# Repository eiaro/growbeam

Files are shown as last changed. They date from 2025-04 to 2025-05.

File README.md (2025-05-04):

# GrowBeam

> A high-efficiency, open-source grow light module for indoor gardeners and hardware hackers.









**GrowBeam** is a modular open-source grow light system designed for indoor gardens, hydroponic setups, and controlled environment agriculture. Each module combines high-efficiency white and deep red LEDs to provide a balanced light spectrum optimized for plant growth.

**NOTE** A test batch is currently ordered. Details to follow soon(tm).

---

## 🌱 Features

- Modular and scalable design
- Uses Samsung LM301H (white) and LUXEON SunPlus 2835 (660 nm red) LEDs
- Designed for 42 V DC input (constant current)
- Simple current-limiting resistor configuration
- Passive cooling (no fans required)
- Easy to manufacture and assemble

## 💡 Light Output & Efficiency

GrowBeam is designed to deliver high photosynthetically active radiation (PAR) while consuming minimal power. Below is a breakdown of light performance based on actual component data:

These values are based on typical LED performance from manufacturer datasheets under standard current levels.

### 🔢 Estimated Output (Per Module)

| Component | Qty | PPF per LED (μmol/s) | Total PPF (μmol/s) |
|---|-----|---|---|
| Samsung LM301H (white) | 72  | ~0.56 | ~40 |
| LUXEON 2835 Deep Red (660 nm) | 15  | ~0.60 | ~9 |
| **Total** | – | – | **~49 μmol/s** |

- **Power consumption:** ~19 W  
- **Photosynthetic Photon Efficacy (PPE):** ~2.60 μmol/J

---

### 🔁 Comparison with Other Light Sources

| Light Source | Power | PPF (μmol/s) | PPE (μmol/J) | Notes |
|---|---|---|---|---|
| **GrowBeam** | ~19 W | ~49 | ~2.6 | High-efficiency DIY module ✅ |
| HPS 400W | 400 W  | ~550 | ~1.4 | High heat, low efficiency ❌ |
| Generic LED Panel (20W) | 20 W | ~15–20 | ~0.75–1.0 | Often misleading specs ❌ |
| T5 Fluorescent Tube (24W) | 24 W | ~28 | ~1.2 | Narrow spectrum, low efficacy ❌ |
| Commercial Grow LED (LM301H) | 100 W | ~270 | ~2.7 | Comparable to GrowBeam ✅ |

---

GrowBeam matches the efficiency of premium grow lights using open hardware and off-the-shelf components — making it a great choice for small to medium-scale indoor growers.

---

## 🛠️ Hardware Overview

Each GrowBeam module contains:
- 6 LED strings with 12 × Samsung LM301H (white)
- 1 LED string with 15 × LUXEON SunPlus 2835 Deep Red

All strings are powered by a shared 42 V DC constant current source and operate at approx. 65 mA per string.

## 📋 Bill of Materials (BoM)

You’ll find a complete part list in `hardware/bom.csv`.  
Key components include:

- 72 × Samsung LM301H white LEDs
- 15 × LUXEON SunPlus 2835 Deep Red LEDs
- Al MCPCB (196 × 35 mm, aluminum-backed recommended)

---

## 📂 Repository Structure
```
growbeam/
├── hardware/
│   ├── kicad_project/           # Contains .kicad_pro, .kicad_sch, .kicad_pcb files, etc.
│   ├── exports/                 # Gerber files, BOM, pick & place, and fabrication outputs
│   └── bom.csv                  # Human-readable bill of materials (optional auto-generated)
├── docs/                        # Additional documentation, test results, diagrams
├── images/                      # Renders, module photos, screenshots
├── LICENSE                      # CERN-OHL v2-S license file
├── README.md                    # Project description and usage guide
├── .gitignore                   # Ignore KiCad backups and build artifacts
└── CONTRIBUTING.md              # (Optional) Contribution guidelines
```

---

## 🧪 Getting Started

1. Clone the repository:  
   `git clone https://github.com/eiaro/growbeam.git`
2. Open the KiCad project in `hardware/kicad_project/`
3. Order parts using the BOM (`hardware/bom.csv`)
4. Assemble and test each module with a 24 V power supply

---

## 📸 Gallery

*(Add photos or renders here)*  
Module example

---

## 📄 License

This project is licensed under the **CERN Open Hardware License v2-S (Strongly Reciprocal)**.  
See the [LICENSE](./LICENSE) file for full terms.

You are free to use, modify, manufacture, and distribute this project, provided that all modifications remain open under the same license.

---

## 🤝 Contributing

Contributions, improvements, and bug reports are welcome!  
If you build your own GrowBeam modules, feel free to share them via issues or pull requests.

## 🙏 Acknowledgements

- Samsung and Lumileds for their detailed datasheets and high-quality horticulture LEDs.
- Open Source Hardware community for inspiration and resources.

## 🌐 Community & Contact

Questions, ideas, or want to showcase your build?  
Open an [issue](https://github.com/eiaro/growbeam/issues) or reach out via [@eiaro](https://github.com/eiaro).

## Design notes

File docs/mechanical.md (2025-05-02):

# 🏗️ Mechanical Design

Modules are mounted on a frame made from aluminum profiles.

## Frame Specification

- 2 vertical and 3 horizontal aluminum profiles
- Fits 5 × 5 modules with even spacing
- Center mounting plate for hanging or support

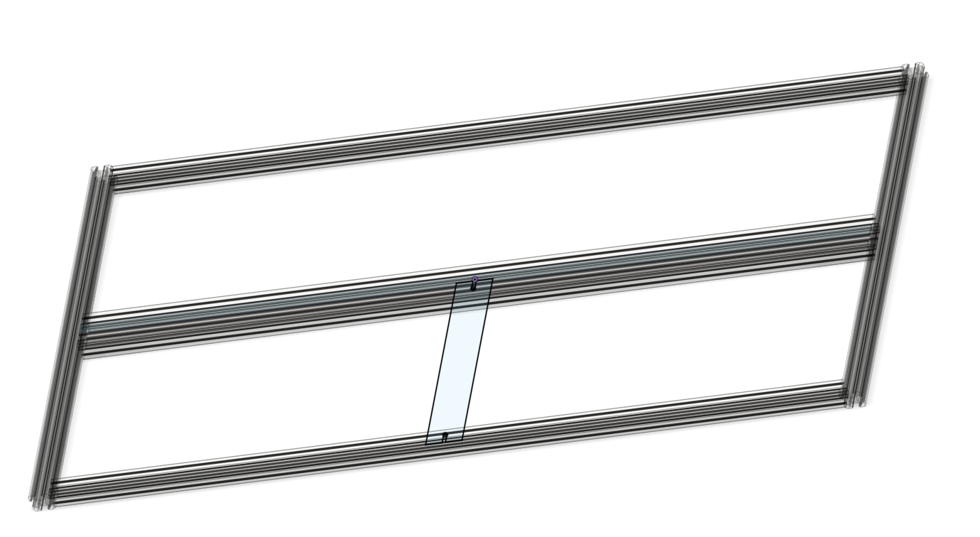
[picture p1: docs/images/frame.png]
Frame


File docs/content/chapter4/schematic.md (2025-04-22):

---
title: "Schematic Design"
weight: 51
---

This section provides an overview of the schematic design for a single GrowBeam LED module.

---

## 📐 Schematic Overview

Schematic

The full schematic is also available as an [PDF file](https://github.com/eiaro/growbeam/blob/main/hardware/exports/schematic.pdf).

---

## 🧾 Bill of Materials (BOM)

The full bill of materials is included as a CSV file:

📄 `hardware/exports/bom.csv`

This file lists all LEDs, resistors, and other components used in each module.

---

## 📏 Resistor Selection Rationale

Each LED string is limited by its own resistor. The values are chosen based on the number of LEDs in series and their forward voltages, using a basic Ohm's Law calculation:

$$
R = \frac{V_{\text{supply}} - V_{\text{LEDs}}}{I}
$$

Where:
- $ V_{\text{supply}} $ is the total supply voltage (24 V)
- $ V_{\text{LEDs}} $ is the combined forward voltage of the LED string
- $ I $ is the target current

| Resistor | LED Count | Estimated \( V_{\text{LEDs}} \) | Resistor Value | Target Drop | Expected Current |
|---|---|---|---|---|---|
| R1–R3 | 7 LEDs | $ 2.75 \text{V} \times 7 = 19.25 \text{V} $ | 75 Ω | ~4.5 V | ~60 mA |
| R4 | 8 LEDs | $ 2.6 \text{V} \times 8 = 20.8 \text{V} $  | 51 Ω | ~3.2 V | ~63 mA |

---

### 🔧 Power Rating

Each resistor needs to dissipate some power:

$$
P = V \times I
$$

For R1–R3:

$$
P \approx 4.5 \text{V} \times 0.06 \text{A} \approx 0.27 \text{W}
$$

For R4:

$$
P \approx 3.2 \text{V} \times 0.063 \text{A} \approx 0.2 \text{W}
$$

To ensure thermal margin and longevity, **0.5 W resistors** are recommended.

---

### ✅ Why Passive Current Limiting?

- No need for active LED drivers
- Easy to test with a multimeter
- Predictable and reliable
- Well-suited for low/medium power modules like GrowBeam

This approach keeps things simple, repairable, and cheap — without sacrificing stability or performance.

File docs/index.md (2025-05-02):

# 🌱 GrowBeam – LED Modules for Plant Lighting

GrowBeam is a modular LED lighting system designed for plant growth. The system consists of 2 × 5 modules mounted on an aluminum frame, powered by a constant current driver from Meanwell.

## Contents

- [Electrical Design](electrical.md)
- [Mechanical Design](mechanical.md)
- [Production](production.md)

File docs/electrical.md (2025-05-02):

# 💡 Electrical Design

## Power Supply

- **Driver:** Meanwell ELG-240-42AB-3Y  
- **Mode:** Constant current  
- **Nominal Output:** 240W @ 42VDC  
- **Set Output Current:** 4.55 A  
- **Configured for 10 modules (5 + 5)**

## LED Configuration

Each module contains:
- 6 strings × 12 white LEDs (SPMWHD32AMH0XAMAPL)
- 1 string × 15 deep red LEDs (L1SP-DRD0002800000)
- Total: 7 LED strings per module, all driven in parallel

Current per module:
- 4.55 A / 10 modules = 455 mA per module
- 455 mA / 7 strings ≈ **65 mA per string**

## Forward Voltage (per string)

| Type | LEDs in series | Est. Vf @ 65 mA | Voltage |
|---|---|---|---|
| White | 12 | ~3.2 V | ~38.4 V |
| Deep Red | 15 | ~2.3 V | ~34.5 V |

All well within the driver's 42 V output limit ✅

## Power and Light Output Per Module

| Type | Count | Current | Power  | Output |
|---|---|---|---|---|
| White LEDs | 72 | 6×65 mA | ~9.9 W | ~1870 lumens |
| Red LEDs | 15 | 1×65 mA | ~2.3 W | ~1.5 W radiant (660 nm) |
| **Total**  | – | 455 mA  | ~12.2 W| ~1870 lm + 1.5 W red |

## System Totals (10 Modules)

- **Total Current:** 4.55 A
- **Total Power:** ~122 W
- **Luminous Output:** ~18,700 lumens
- **660 nm Radiant Power:** ~15 W

## PPF (Photosynthetic Photon Flux)

- White: 1870 lm / 70 ≈ **26.7 μmol/s**
- Red: 1.5 W × 4.58 μmol/s/W ≈ **6.87 μmol/s**
- **PPF per module:** ~33.6 μmol/s
- **Total PPF (10 modules):** **~336 μmol/s**

## PPFD in 90×60 cm Grow Tent

Tent area: 0.9 m × 0.6 m = **0.54 m²**

\[
\text{PPFD} = \frac{336\,μmol/s}{0.54\,m²} ≈ 	extbf{622 μmol/m²/s}
\]

### Summary

| Application | Recommended PPFD | Your PPFD | Outcome |
|---|---|---|---|
| Microgreens / Lettuce | 100–400 | ✅ 622 | Excellent growth |
| Tomatoes / Peppers | 600–900 | ✅ 622 | Very good / near optimal |
| Cannabis Flowering | 800–1000 | ⚠️ 622 | Slightly low, still usable |

This system provides powerful and efficient lighting for high-performance plant growth in a compact 90×60 cm grow space.

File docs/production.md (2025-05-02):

# 🔧 Production

## PCB

- PCB size: 196 mm × 35 mm
- Mounting holes for screw attachment to the frame
- Silkscreen with LED type and polarity

## Assembly

- LEDs are mounted using reflow soldering
- Modules are screwed to the aluminum frame
- Wires are soldered and connected to +VDC and –VDC

## Operation & Safety

- The system is powered only via Meanwell ELG-240-42AB-3Y
- Ensure proper heat dissipation via the frame and/or heatsinks
- Do not operate without connected load

## Future Plans

- Temperature monitoring per module
- PWM dimming via analog input on the driver
- Sensor-based light control

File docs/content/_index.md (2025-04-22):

---
title: GrowBeam
description: Modular LED lighting system for horticulture
---

# 🌱 GrowBeam

GrowBeam is an open hardware project focused on building **modular, efficient, and DIY-friendly LED lighting** for indoor horticulture. Whether you're growing microgreens on a windowsill or managing a full-sized grow tent, GrowBeam aims to provide:

- 🧩 Modular design to fit any tent or tray size  
- 💡 High-efficiency horticulture-grade LEDs  
- 🔧 Simple, fanless thermal design  
- 🛠️ Fully documented: schematics, BOM, 3D models, and rationale  

---

## 🚀 Getting Started

Check the [Getting Started](/chapter1) section to set up the hardware or explore the system design under [Components & Technologies](/chapter4).

---

## 📚 Structure

- **[Background & Motivation](/chapter2)** — Why this project exists
- **[Components](/chapter3)** — LED types, power delivery, mechanical parts
- **[Design & Decisions](/chapter4)** — What we chose and why
- **[Schematic](/chapter4/schematic)** — Circuit overview and BOM
- **[Results & Future](/chapter5)** — Performance, learnings, and roadmap

---

## 💬 Contribute or Learn More

GrowBeam is open to contributions! You can:

- Fork the [GitHub repo](https://github.com/eiaro/growbeam)
- Open issues, suggest improvements, or document your own builds
- Join the discussion and help improve open horticulture lighting!

---

> ⚠️ **Disclaimer**: This project is experimental. Always test electronics for safety and suitability before long-term use in grow environments.

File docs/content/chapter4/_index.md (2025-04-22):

---
title: "Chapter 4 - Design and Decisions"
weight: 50
---

This section documents the design strategies and component choices that were evaluated during the early phases of the GrowBeam project, and why they were ultimately rejected or not chosen.

---

## Light Sources

### ❌ Preassembled LED Strips

**Pros:**
- Cheap and widely available
- Easy to apply and cut to length

**Cons:**
- Low efficiency (~1.0–1.5 µmol/J)
- Poor heat dissipation
- Not horticulture-specific spectrum
- Adhesives fail in humid environments

→ **Rejected** due to lack of durability and light quality.

---

### ❌ Larger MCPCBs (Starboards or Panels)

**Pros:**
- Pre-mounted horticulture LEDs
- Simplifies PCB design

**Cons:**
- Fixed layout; not modular
- Often pre-bundled with unsuitable drivers
- Higher cost per µmol

→ **Rejected** due to poor fit for custom tent dimensions.

---

### ❌ Parallel COB Panels

**Pros:**
- Very high light output
- Fewer components and drivers

**Cons:**
- Localized heat, needs large heatsinks
- Poor uniformity without optics
- Inflexible layout

→ **Rejected** due to heat and canopy coverage limitations.

---

### ✅ Discrete LEDs on Modular Bars

- Multiple low-power LEDs evenly spaced
- Passive cooling via aluminum extrusion
- Flexible layout for tents of various sizes
- Balanced white and red spectrum control

→ **Eventually chosen** for optimal balance of output, cost, and mechanical flexibility.

---

## Dimensions

It was clear from the beginning that some kind of structural support would be necessary, and aluminum offers both mechanical rigidity and excellent thermal conductivity.

The width of **20 mm** aligns with commonly available flatbars and U- or L-profiles. The **150 mm length** was chosen as a compromise between:
- Manufacturability using standard aluminum lengths
- Alignment with common grow tent dimensions (multiples of 30/60/90/120 cm)

**Thermal Fit:** Each module offers enough surface area to passively dissipate the heat generated by the LEDs.  
**Mechanical Simplicity:** Fits standard aluminum U-channels without custom machining.  
**Modular Flexibility:** Example layout: 4 modules x 150 mm = 600 mm length × 5 rows = 90 cm width — ideal for a 90×60 cm grow tent.

---

## LED Selection and Count

The primary performance goal is to exceed a 400W CFL, which corresponds to a Photosynthetic Photon Flux (PPF) of around **240 µmol/s**.

By distributing this across **20 modules**, each module must contribute at least **12 µmol/s**. Based on LED datasheets and real-world test reports, this output can be achieved with:
- **21 × Samsung LM301H** (white)
- **9 × LUXEON SunPlus 2835** (660 nm red)

These LEDs were selected for their:
- High photon efficacy (over 2.9 µmol/J for LM301H)
- Proven horticultural performance
- Readily available small-quantity distribution (e.g., via DigiKey, Mouser)

> Availability is an often-overlooked design constraint. While reels of 4000 LEDs may be cost-effective per unit, they lock out hobbyists and prototypes. Choosing widely stocked horticulture-grade LEDs ensures GrowBeam can be built by individuals without industry-scale procurement.

---

## Summary

GrowBeam’s design was guided by a few clear principles:
- Maximize photon efficiency with passive cooling
- Adapt easily to irregular tent sizes
- Rely on components available to hobbyists and small-scale builders

These goals shaped everything from the LED layout to the mechanical frame. The result is a grow light system that is simple, scalable, and surprisingly powerful — without the noise, bulk, or inefficiencies of legacy lighting.

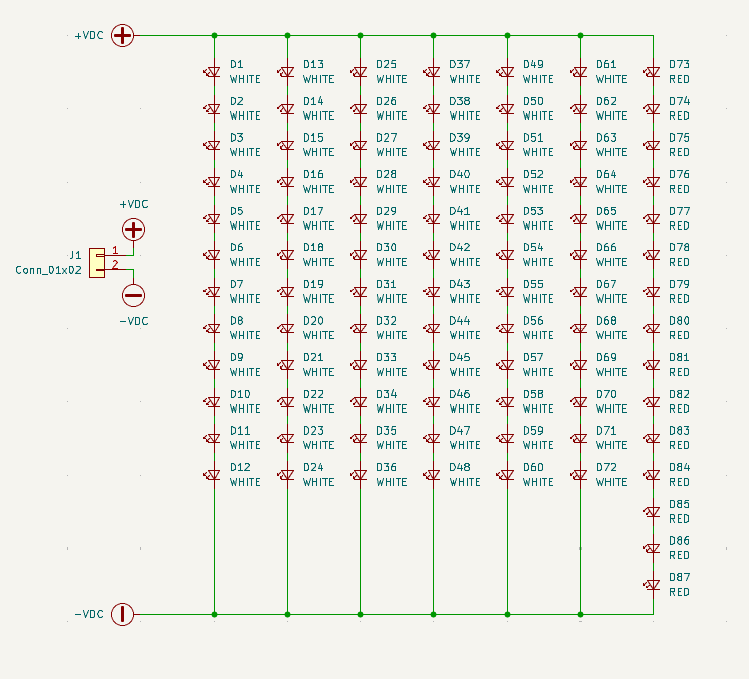
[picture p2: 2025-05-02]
docs/images/schematic.png

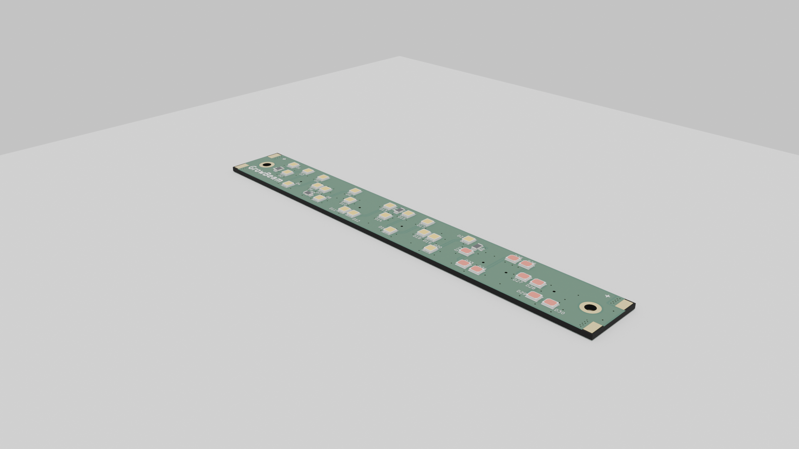
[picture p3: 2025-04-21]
hardware/exports/growbeam.png

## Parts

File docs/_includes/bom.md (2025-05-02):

| Reference | Qty | Value | DNP | Exclude from BOM | Exclude from Board | Footprint | Datasheet |
|:---|---:|:---|---:|:---|---:|:---|:---|
| D1-D72 | 72 | WHITE | nan | nan | nan | LED_LM301H:LED_LM301H_1212 | ~ |
| D73-D87 | 15 | RED | nan | nan | nan | LED_LUMILEDS:LED-SP2835-LUMILEDS | ~ |
| H1,H2 | 2 | MountingHole | nan | Excluded from BOM  | nan | MountingHole:MountingHole_2.7mm_M2.5_DIN965_Pad | ~ |
| J1 | 1 | Conn_01x02 | nan | nan | nan | TerminalBlock_WAGO:WAGO_2060-452_998-404 | ~ |

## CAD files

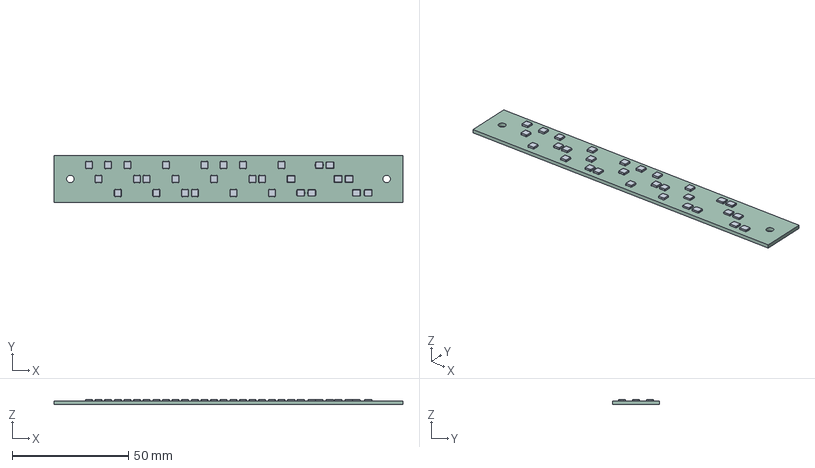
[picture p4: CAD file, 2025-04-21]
hardware/exports/growbeam.step
150.0 x 20.0 x 2.34 mm
LM301H x 21
LUXEON_SP_2835 x 9
growbeam_PCB

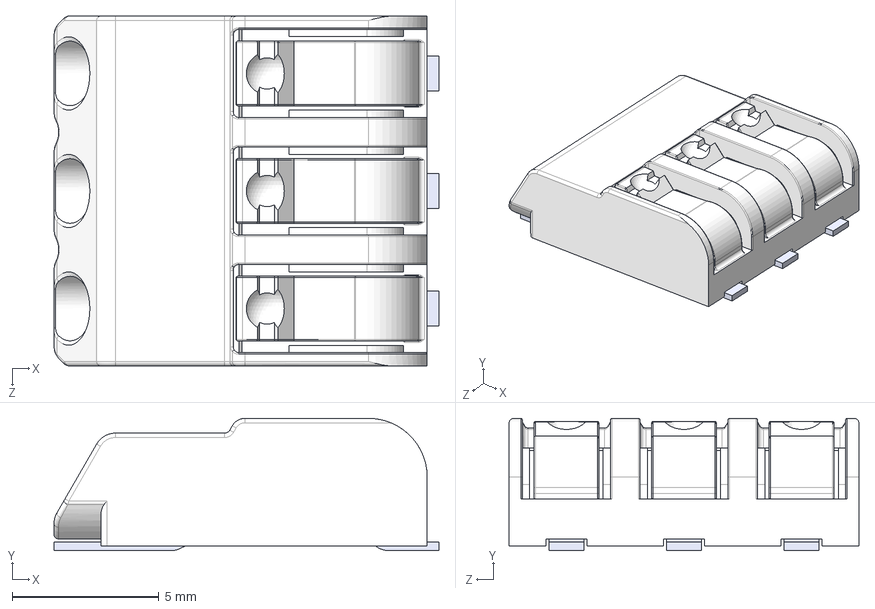
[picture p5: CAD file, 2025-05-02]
hardware/GB-v2-87L/3dmodels/2060-453_998-404.step
13.1 x 4.50 x 11.9 mm

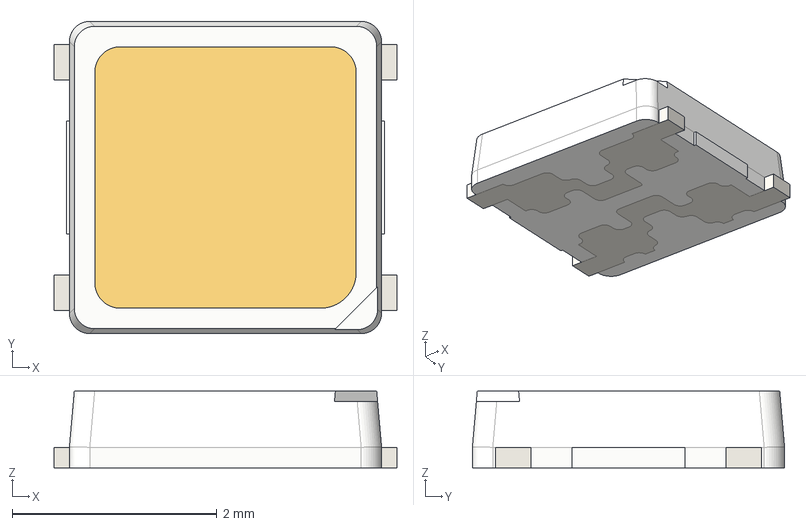
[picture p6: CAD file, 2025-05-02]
hardware/GB-v2-87L/3dmodels/LM301H.stp
3.35 x 3.05 x 0.751 mm

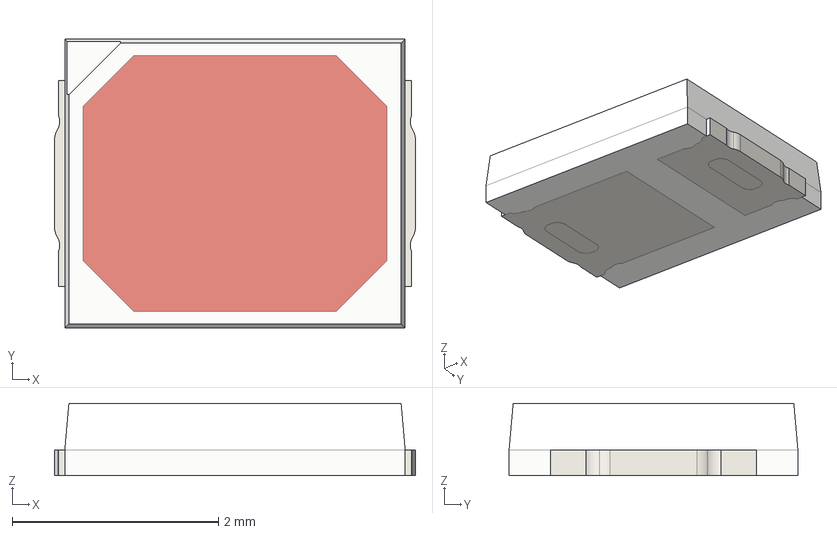
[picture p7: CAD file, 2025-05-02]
hardware/GB-v2-87L/3dmodels/LUXEON_SP_2835.stp
3.50 x 2.80 x 0.701 mm

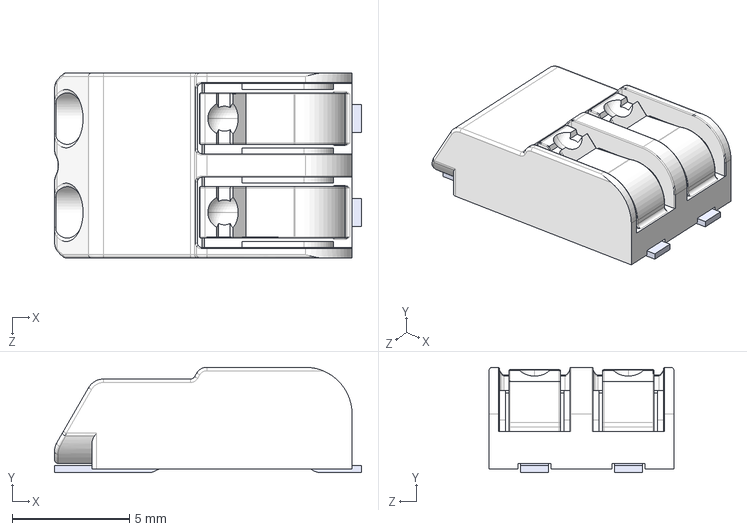
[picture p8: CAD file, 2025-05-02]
hardware/GB-v2-87L/3dmodels/2060-452_998-404.step
13.1 x 4.50 x 7.90 mm

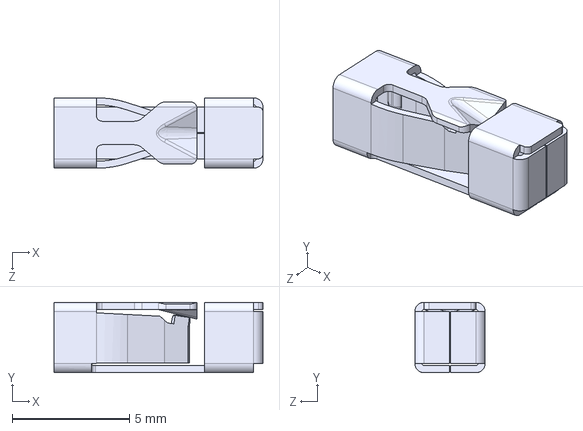
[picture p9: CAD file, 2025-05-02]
hardware/GB-v2-87L/3dmodels/2834167-3.step
8.90 x 3.00 x 3.00 mm

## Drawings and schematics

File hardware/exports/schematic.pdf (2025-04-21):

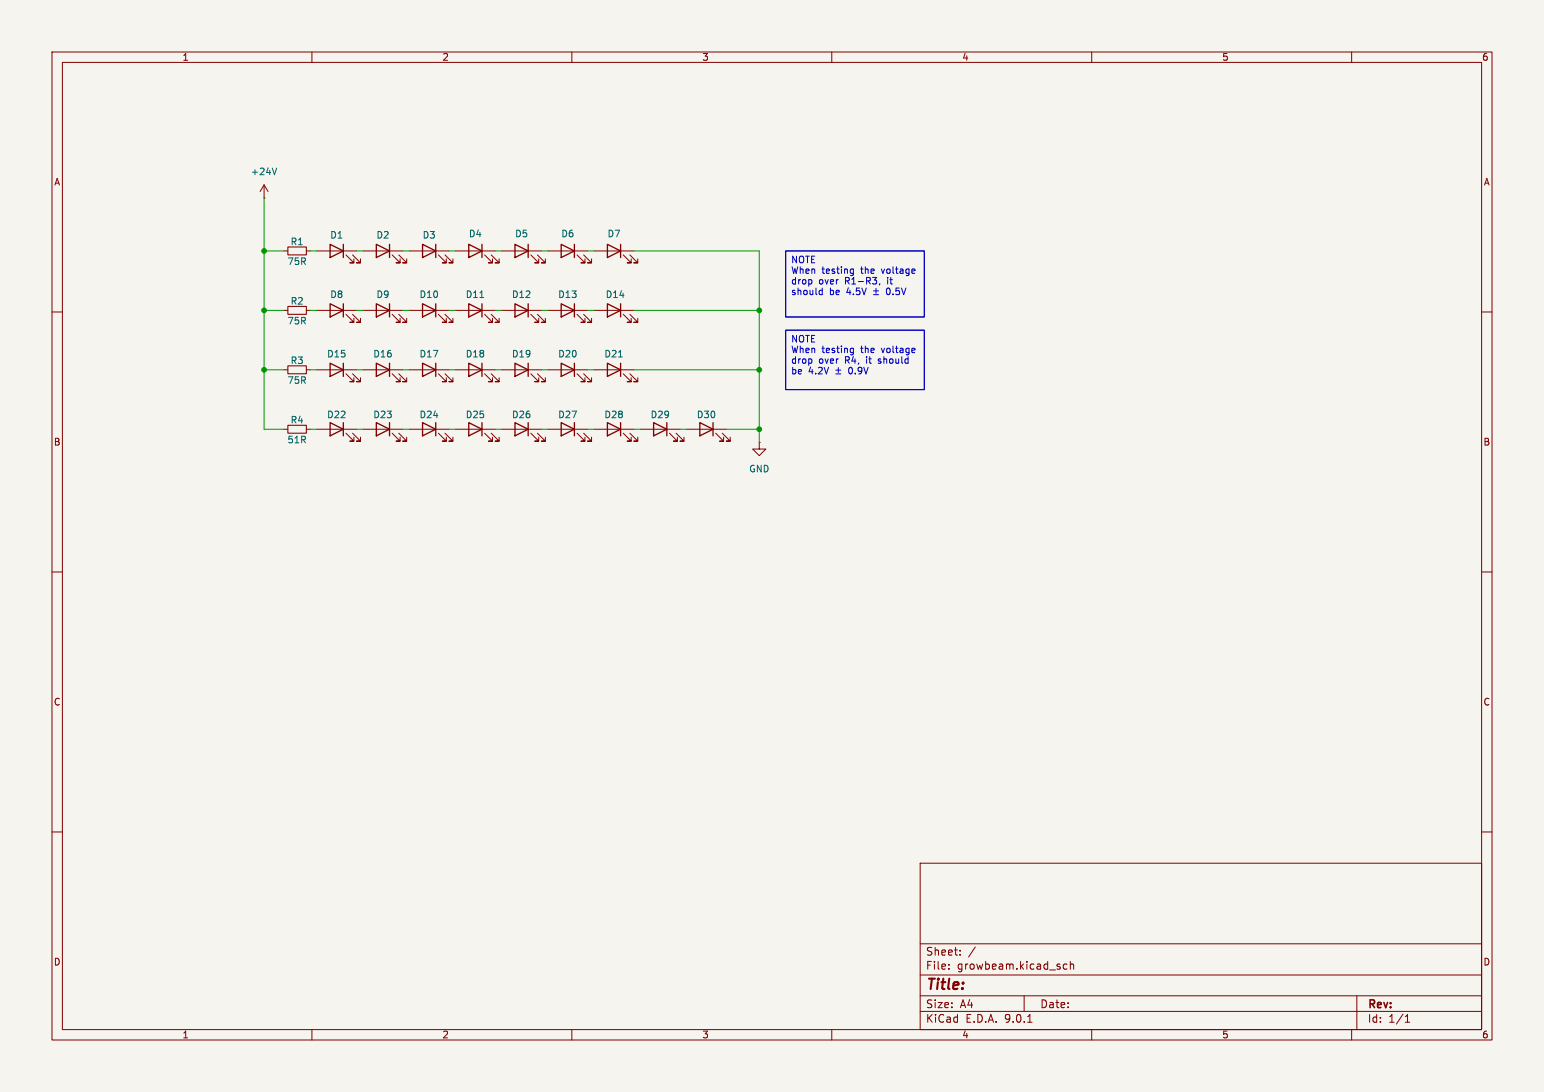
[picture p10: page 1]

NOTE When testing the voltage

drop over R4, it should

Id: 1/1 Title: File: growbeam.kicad_sch Sheet: /

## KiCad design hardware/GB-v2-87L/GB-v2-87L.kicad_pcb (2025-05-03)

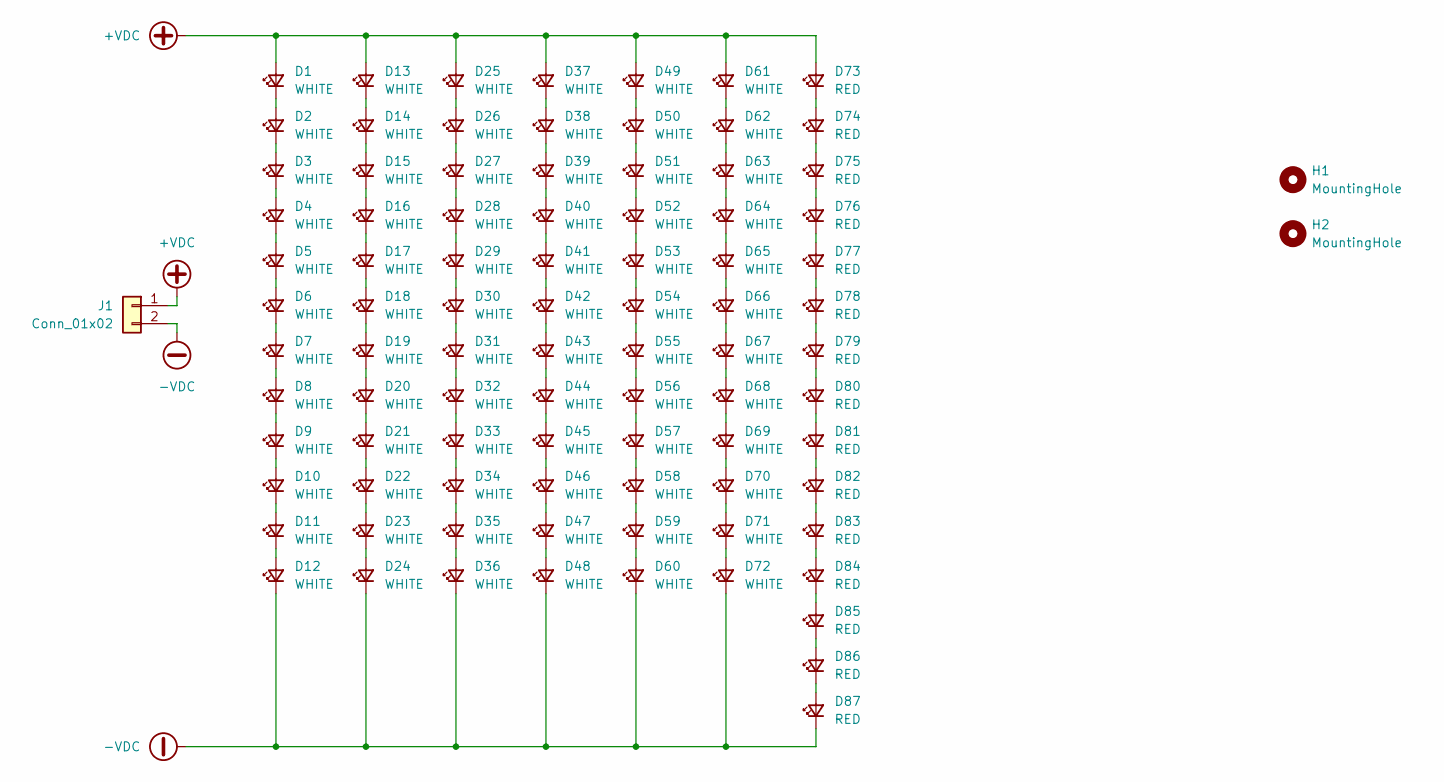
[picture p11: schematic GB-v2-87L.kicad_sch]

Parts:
D1, D2, D3, D4, D5, D6, D7, D8, D9, D10, D11, D12, D13, D14, D15, D16, D17, D18, D19, D20, D21, D22, D23, D24, D25, D26, D27, D28, D29, D30, D31, D32, D33, D34, D35, D36, D37, D38, D39, D40, D41, D42, D43, D44, D45, D46, D47, D48, D49, D50, D51, D52, D53, D54, D55, D56, D57, D58, D59, D60, D61, D62, D63, D64, D65, D66, D67, D68, D69, D70, D71, D72: WHITE; LED_LM301H_1212
D73, D74, D75, D76, D77, D78, D79, D80, D81, D82, D83, D84, D85, D86, D87: RED; LED-SP2835-LUMILEDS
H1, H2: MountingHole; MountingHole_2.7mm
J1: Conn_01x02; WAGO_2060-452_998-404

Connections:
+VDC: D1.2 (A), D13.2 (A), D25.2 (A), D37.2 (A), D49.2 (A), D61.2 (A), D73.2 (A), J1.1
-VDC: D12.1 (K), D24.1 (K), D36.1 (K), D48.1 (K), D60.1 (K), D72.1 (K), D87.1 (K), J1.2
unnamed: D1.1 (K), D2.2 (A)
unnamed: D2.1 (K), D3.2 (A)
unnamed: D3.1 (K), D4.2 (A)
unnamed: D4.1 (K), D5.2 (A)
unnamed: D5.1 (K), D6.2 (A)
unnamed: D6.1 (K), D7.2 (A)
unnamed: D7.1 (K), D8.2 (A)
unnamed: D8.1 (K), D9.2 (A)
unnamed: D9.1 (K), D10.2 (A)
unnamed: D10.1 (K), D11.2 (A)
unnamed: D11.1 (K), D12.2 (A)
unnamed: D13.1 (K), D14.2 (A)
unnamed: D14.1 (K), D15.2 (A)
unnamed: D15.1 (K), D16.2 (A)
unnamed: D16.1 (K), D17.2 (A)
unnamed: D17.1 (K), D18.2 (A)
unnamed: D18.1 (K), D19.2 (A)
unnamed: D19.1 (K), D20.2 (A)
unnamed: D20.1 (K), D21.2 (A)
unnamed: D21.1 (K), D22.2 (A)
unnamed: D22.1 (K), D23.2 (A)
unnamed: D23.1 (K), D24.2 (A)
unnamed: D25.1 (K), D26.2 (A)
unnamed: D26.1 (K), D27.2 (A)
unnamed: D27.1 (K), D28.2 (A)
unnamed: D28.1 (K), D29.2 (A)
unnamed: D29.1 (K), D30.2 (A)
unnamed: D30.1 (K), D31.2 (A)
unnamed: D31.1 (K), D32.2 (A)
unnamed: D32.1 (K), D33.2 (A)
unnamed: D33.1 (K), D34.2 (A)
unnamed: D34.1 (K), D35.2 (A)
unnamed: D35.1 (K), D36.2 (A)
unnamed: D37.1 (K), D38.2 (A)
unnamed: D38.1 (K), D39.2 (A)
unnamed: D39.1 (K), D40.2 (A)
unnamed: D40.1 (K), D41.2 (A)
unnamed: D41.1 (K), D42.2 (A)
unnamed: D42.1 (K), D43.2 (A)
unnamed: D43.1 (K), D44.2 (A)
unnamed: D44.1 (K), D45.2 (A)
unnamed: D45.1 (K), D46.2 (A)
unnamed: D46.1 (K), D47.2 (A)
unnamed: D47.1 (K), D48.2 (A)
unnamed: D49.1 (K), D50.2 (A)
unnamed: D50.1 (K), D51.2 (A)
unnamed: D51.1 (K), D52.2 (A)
unnamed: D52.1 (K), D53.2 (A)
unnamed: D53.1 (K), D54.2 (A)
unnamed: D54.1 (K), D55.2 (A)
unnamed: D55.1 (K), D56.2 (A)
unnamed: D56.1 (K), D57.2 (A)
unnamed: D57.1 (K), D58.2 (A)
unnamed: D58.1 (K), D59.2 (A)
unnamed: D59.1 (K), D60.2 (A)
unnamed: D61.1 (K), D62.2 (A)
unnamed: D62.1 (K), D63.2 (A)
unnamed: D63.1 (K), D64.2 (A)
unnamed: D64.1 (K), D65.2 (A)
unnamed: D65.1 (K), D66.2 (A)
unnamed: D66.1 (K), D67.2 (A)
unnamed: D67.1 (K), D68.2 (A)
unnamed: D68.1 (K), D69.2 (A)
unnamed: D69.1 (K), D70.2 (A)
unnamed: D70.1 (K), D71.2 (A)
unnamed: D71.1 (K), D72.2 (A)
unnamed: D73.1 (K), D74.2 (A)
unnamed: D74.1 (K), D75.2 (A)
unnamed: D75.1 (K), D76.2 (A)
unnamed: D76.1 (K), D77.2 (A)
unnamed: D77.1 (K), D78.2 (A)
unnamed: D78.1 (K), D79.2 (A)
unnamed: D79.1 (K), D80.2 (A)
unnamed: D80.1 (K), D81.2 (A)
unnamed: D81.1 (K), D82.2 (A)
unnamed: D82.1 (K), D83.2 (A)
unnamed: D83.1 (K), D84.2 (A)
unnamed: D84.1 (K), D85.2 (A)
unnamed: D85.1 (K), D86.2 (A)
unnamed: D86.1 (K), D87.2 (A)

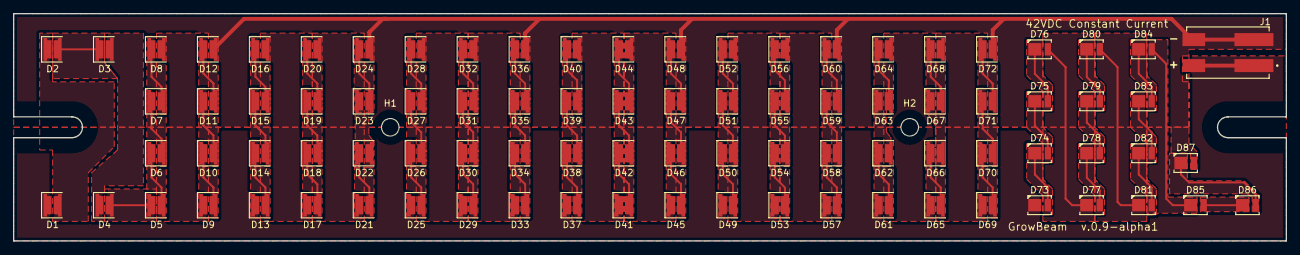
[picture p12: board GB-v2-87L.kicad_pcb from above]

Board: 2 copper layers, 196.0 x 35.0 mm, 90 parts (0 on the bottom side), 82 nets.

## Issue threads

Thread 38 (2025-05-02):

Is the PCB ready for production?

madushan1000, 2025-05-02:
Is this ready for production? I'm thinking of getting some jlcpcb aluminum PCBs made.
Where did you source the components from, especially LM301H? I found some sources for LM301B on aliexpress which I think would work okay too. But I'm not totally sure.

eiaro, 2025-05-02:
I will be ordering the next few days. I'd wait until I had a working example as they are quite expensive.

LM301H was sourced from DigiKey. The difference to LM301B is minimal, but both types is known to be counterfeited.

madushan1000, 2025-05-03:
Thank you, let me know when you have it working. I'll order some after that.
I saw LM301H was available on digikey, but shipping charges are very high :/

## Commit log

2025-04-17 Changed footprint for L1SP. Added color 3D models. Rerouted after changed footprints.
    [LM301H.stp, LUXEON_SP_2835.stp, growlight-module.kicad_pcb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]
2025-04-18 renaming files for my ocd
    [growbeam.kicad_pcb, growbeam.kicad_sch]
2025-04-18 my ocd
    [growlight-module.kicad_pcb, growlight-module.kicad_sch]
2025-04-18 Remove unused KiCad project file for growlight module
2025-04-18 Update commit-exports.yml
    bom.csv should be generated and not uploaded, so we keep the .gitignore and add a -f flag.
2025-04-18 Remove dummy test files from kicad_project
2025-04-18 Add dummy file to kicad_project for placeholder purposes
2025-04-18 Update dummy file in kicad_project to specify version
2025-04-18 Update dummy file in kicad_project to change content
2025-04-18 Auto-generate files after ERC/DRC checks
    [bom.csv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]
2025-04-19 Fix Dockerfile to specify full image path for KiCad
2025-04-19 Add FreeCAD and Blender steps for STEP to STL conversion and rendering
2025-04-19 Fix KiCad commands in export workflow for ERC and DRC checks
2025-04-19 Add missing exports for growbeam.stl and growbeam.png in workflow
2025-04-21 Refactor Dockerfile to use Ubuntu base image and streamline installation of dependencies for KiCad, Blender, and FreeCAD
2025-04-21 Remove deprecated rendering scripts for STEP to STL and PNG conversion
2025-04-21 Update ERC exclusions and correct filename in KiCad project
2025-04-21 Fix via position in KiCad PCB layout
    [growbeam.kicad_pcb]
2025-04-21 Remove unused dummy file from KiCad project
2025-04-21 Add rectangular outline to LED footprint for improved visibility
2025-04-21 Implement new pcb land and a few adjustments
    [growbeam.kicad_pcb]
2025-04-23 Refactor export process in GitHub Actions and Makefile: streamline KiCad file exports and update image reference
2025-04-23 Fix image reference in schematic documentation: update Schematic image path to relative URL
2025-04-23 Refactor documentation and add BOM generation script
    - Removed the Table of Contents from components index.
    - Updated the schematic documentation to reference the BOM markdown file.
    - Corrected the link for Background & Motivation in the main index.
    - Added MathJax configuration for rendering mathematical expressions.
    - Included extra JavaScript file for MathJax in mkdocs configuration.
    - Created a new Python script to generate BOM in markdown format from CSV.
2025-04-23 Update .gitignore, Makefile, Dockerfile, and documentation: add virtual environment, streamline export processes, and include BOM in documentation
2025-04-23 Enhance BOM configuration: add presets for BOM export with detailed field settings and grouping options
2025-04-23 Fix BOM Markdown generation by ensuring the output directory exists
2025-04-23 Fix typo in Makefile: change 'makedir' to 'mkdir' for BOM Markdown generation
2025-05-02 Refactor code structure for improved readability and maintainability
    [LM301H.stp, LUXEON_SP_2835.stp, bom.csv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]
2025-05-02 Add new footprints and symbols for various components
    - Created footprint for LED-SP2835-LUMILEDS with detailed properties and dimensions.
    - Added footprint for TE_2834167-3 terminal block with appropriate pads and silk screen.
    - Introduced WAGO_2060-452_998-404 and WAGO_2060-453_998-404 footprints with defined pads and outlines.
    - Updated fp-lib-table to include new libraries for LED and terminal blocks.
    - Added sym-lib-table for new symbols related to WAGO terminal blocks.
    - Created symbols for WAGO_2060-452_998-404 and WAGO_2060-453_998-404 with relevant properties and pin configurations.
    [2060-452_998-404.step, 2060-453_998-404.step, 2834167-3.step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]
2025-05-02 Update schematic and PCB paths in Makefile to reflect new project structure
2025-05-02 Add mechanical design and production documentation
    - Created mechanical design documentation outlining the frame specifications for module mounting.
    - Added production documentation detailing PCB specifications, assembly instructions, operation and safety guidelines, and future plans for enhancements.
    - Included a lock file for the schematic to track user access.
2025-05-02 Update GrowBeam documentation and hardware configuration
    - Changed the module configuration in the documentation from 5 × 5 to 2 × 5.
    - Removed extensive default settings and rules from the KiCad project file to streamline the configuration.
    - Adjusted track width from 0.3 to 0.2 in the KiCad project.
    - Updated BOM presets to include detailed fields for better organization and clarity.
    - Modified label size ratio and text offset ratio for improved readability in the schematic.
2025-05-03 - Introduced a new footprint for a 2.7mm mounting hole in the ProjectSpecific library. - Updated schematic references to use the new footprint instead of the previous generic mounting hole.
    [GB-v2-87L.kicad_pcb, GB-v2-87L.kicad_sch]
2025-05-04 Update light output and power consumption values in README.md

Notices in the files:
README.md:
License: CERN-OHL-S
